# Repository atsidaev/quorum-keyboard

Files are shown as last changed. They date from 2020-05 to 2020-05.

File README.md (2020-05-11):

# Мини-клавиатура для Кворум-128

Пленка в клавиатуре Кворума-128 не очень прочна и много у кого уже умерла. На правах костыля можно заменить такую клавиатуру
на текстолитовый суррогат. Для установки требуется выпаять оргинальные разъемы и заменить их на штыри PLS.

# Mini-keyboard for Quorum-128 computer (Russian clone of ZX Spectrum)

Quorum-128 keyboard film is not very durable. But despite the Sinclair ZX Spectrum film, it cannot be simply bought on eBay.
So more radical solution is required.

This repo contains KiCad sources for very small repalcement keyboard. To install it one should replace film connector with
PLS pins.

## Explanation and soldering video

Youtube link (https://www.youtube.com/watch?v=iXpktqWTcs8)

## Photos
  
  
  
  
  

## Gerbers

See Releases tab. 
[Latest version](https://github.com/atsidaev/quorum_keyboard/releases/download/v1.0/quorum-keyboard.zip)

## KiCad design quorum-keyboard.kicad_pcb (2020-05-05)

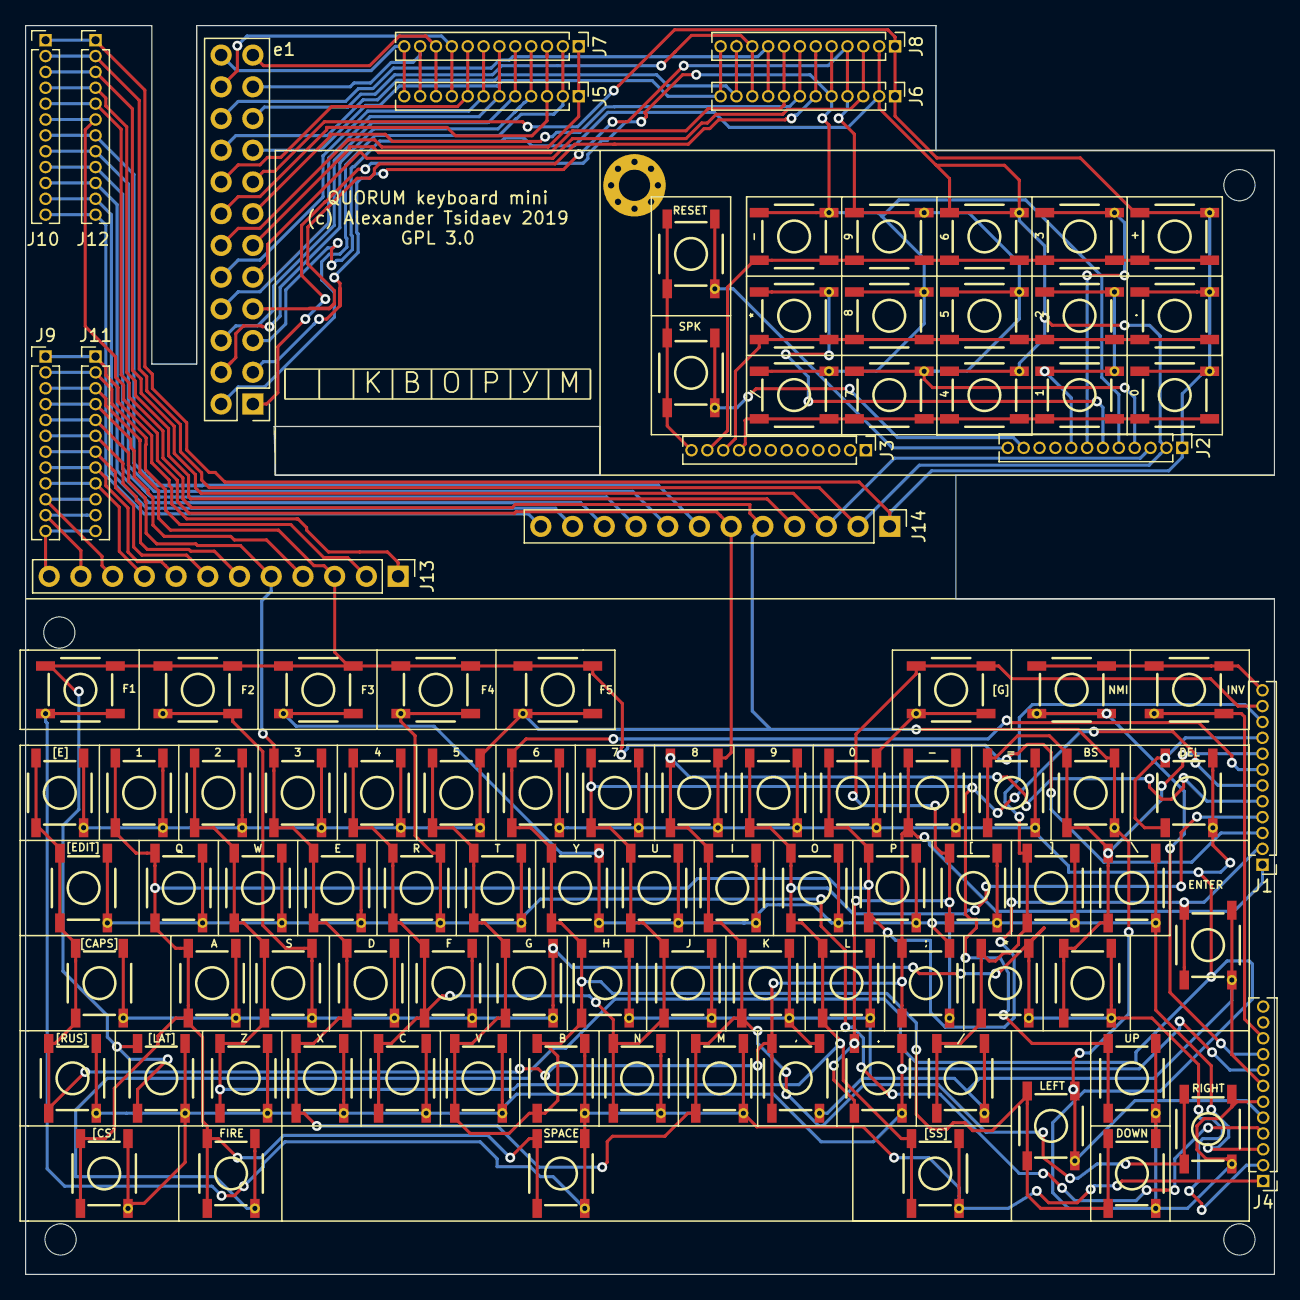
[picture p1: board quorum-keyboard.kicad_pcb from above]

Board: 2 copper layers, 100.0 x 100.0 mm, 107 parts (0 on the bottom side), 24 nets.

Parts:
0, 0#2, 1, 1#2, 2, 2#2, 3, 3#2, 4, 4#2, 5, 5#2, 6, 6#2, 7, 7#2, 8, 8#2, 9, 9#2, ., .#2: QKB_TACTILE_SWITCH_SMD_5.2MM
 : MountingHole_2.5mm
 #2,  #3: MountingHole_2.5mm
*: QKB_TACTILE_SWITCH_SMD_5.2MM
*#2: QKB_TACTILE_SWITCH_SMD_5.2MM
+: QKB_TACTILE_SWITCH_SMD_5.2MM
,: QKB_TACTILE_SWITCH_SMD_5.2MM
-: QKB_TACTILE_SWITCH_SMD_5.2MM
-#2: QKB_TACTILE_SWITCH_SMD_5.2MM
/: QKB_TACTILE_SWITCH_SMD_5.2MM
/#2: QKB_TACTILE_SWITCH_SMD_5.2MM
;: QKB_TACTILE_SWITCH_SMD_5.2MM
=: QKB_TACTILE_SWITCH_SMD_5.2MM
A: QKB_TACTILE_SWITCH_SMD_5.2MM
B: QKB_TACTILE_SWITCH_SMD_5.2MM
BS: QKB_TACTILE_SWITCH_SMD_5.2MM
C: QKB_TACTILE_SWITCH_SMD_5.2MM
D: QKB_TACTILE_SWITCH_SMD_5.2MM
DEL: QKB_TACTILE_SWITCH_SMD_5.2MM
DOWN: QKB_TACTILE_SWITCH_SMD_5.2MM
E: QKB_TACTILE_SWITCH_SMD_5.2MM
ENTER: QKB_TACTILE_SWITCH_SMD_5.2MM
F, F1, F2, F3, F4, F5: QKB_TACTILE_SWITCH_SMD_5.2MM
FIRE: QKB_TACTILE_SWITCH_SMD_5.2MM
G: QKB_TACTILE_SWITCH_SMD_5.2MM
H: QKB_TACTILE_SWITCH_SMD_5.2MM
H3: MountingHole_2.5mm
H4: MountingHole_2.5mm_Pad_Via
I: QKB_TACTILE_SWITCH_SMD_5.2MM
INV: QKB_TACTILE_SWITCH_SMD_5.2MM
J: QKB_TACTILE_SWITCH_SMD_5.2MM
J1, J2, J3, J4, J5, J6, J7, J8, J9, J10, J11, J12: Pin_Header_Straight_1x12_Pitch1.27mm
J13, J14: Pin_Header_Straight_1x12_Pitch2.54mm
K: QKB_TACTILE_SWITCH_SMD_5.2MM
L: QKB_TACTILE_SWITCH_SMD_5.2MM
LEFT: QKB_TACTILE_SWITCH_SMD_5.2MM
M: QKB_TACTILE_SWITCH_SMD_5.2MM
N: QKB_TACTILE_SWITCH_SMD_5.2MM
NMI: QKB_TACTILE_SWITCH_SMD_5.2MM
O: QKB_TACTILE_SWITCH_SMD_5.2MM
P: QKB_TACTILE_SWITCH_SMD_5.2MM
Q: QKB_TACTILE_SWITCH_SMD_5.2MM
R: QKB_TACTILE_SWITCH_SMD_5.2MM
RESET: QKB_TACTILE_SWITCH_SMD_5.2MM
RIGHT: QKB_TACTILE_SWITCH_SMD_5.2MM
S: QKB_TACTILE_SWITCH_SMD_5.2MM
SPACE: QKB_TACTILE_SWITCH_SMD_5.2MM
SPK: QKB_TACTILE_SWITCH_SMD_5.2MM
T: QKB_TACTILE_SWITCH_SMD_5.2MM
U: QKB_TACTILE_SWITCH_SMD_5.2MM
UP: QKB_TACTILE_SWITCH_SMD_5.2MM
V: QKB_TACTILE_SWITCH_SMD_5.2MM
W: QKB_TACTILE_SWITCH_SMD_5.2MM
X: QKB_TACTILE_SWITCH_SMD_5.2MM
Y: QKB_TACTILE_SWITCH_SMD_5.2MM
Z: QKB_TACTILE_SWITCH_SMD_5.2MM
[: QKB_TACTILE_SWITCH_SMD_5.2MM
[CAPS]: QKB_TACTILE_SWITCH_SMD_5.2MM
[CS]: QKB_TACTILE_SWITCH_SMD_5.2MM
[EDIT]: QKB_TACTILE_SWITCH_SMD_5.2MM
[E]: QKB_TACTILE_SWITCH_SMD_5.2MM
[G]: QKB_TACTILE_SWITCH_SMD_5.2MM
[LAT]: QKB_TACTILE_SWITCH_SMD_5.2MM
[RUS]: QKB_TACTILE_SWITCH_SMD_5.2MM
[SS]: QKB_TACTILE_SWITCH_SMD_5.2MM
\: QKB_TACTILE_SWITCH_SMD_5.2MM
]: QKB_TACTILE_SWITCH_SMD_5.2MM
e1: Pin_Header_Straight_2x12_Pitch2.54mm

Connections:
A8: 1.3, 1.4, 2.3, 2.4, .#2.3, .#2.4, C.3, C.4, J2.8, J4.8, J6.8, J8.8, J10.8, J12.8, J14.8, V.3, V.4, X.3, X.4, Z.3, Z.4, [CS].3, [CS].4, [LAT].3, [LAT].4, [RUS].3, [RUS].4, e1.11
A9: 4.3, 4.4, 6.3, 6.4, *#2.3, *#2.4, A.3, A.4, D.3, D.4, F.3, F.4, F2.3, F2.4, G.3, G.4, J2.2, J4.2, J6.2, J8.2, J10.2, J12.2, J14.2, S.3, S.4, [CAPS].3, [CAPS].4, e1.5
A10: 5.3, 5.4, 7.3, 7.4, 9.3, 9.4, E.3, E.4, F4.3, F4.4, J2.4, J4.4, J6.4, J8.4, J10.4, J12.4, J14.4, Q.3, Q.4, R.3, R.4, T.3, T.4, W.3, W.4, [EDIT].3, [EDIT].4, e1.3
A11: 1#2.3, 1#2.4, 2#2.3, 2#2.4, 3#2.3, 3#2.4, 4#2.3, 4#2.4, 5#2.3, 5#2.4, 8.3, 8.4, -.3, -.4, /.3, /.4, BS.3, BS.4, F5.3, F5.4, J2.5, J4.5, J6.5, J8.5, J10.5, J12.5, J14.5, LEFT.3, LEFT.4, [E].3, [E].4, e1.1
A12: 0#2.3, 0#2.4, 6#2.3, 6#2.4, 7#2.3, 7#2.4, 8#2.3, 8#2.4, 9#2.3, 9#2.4, *.3, *.4, -#2.3, -#2.4, =.3, =.4, DEL.3, DEL.4, DOWN.3, DOWN.4, FIRE.3, FIRE.4, J2.6, J4.6, J6.6, J8.6, J10.6, J12.6, J14.6, RIGHT.3, RIGHT.4, UP.3, UP.4, [G].3, [G].4, e1.7
A13: ;.3, ;.4, F3.3, F3.4, I.3, I.4, J2.3, J4.3, J6.3, J8.3, J10.3, J12.3, J14.3, O.3, O.4, P.3, P.4, U.3, U.4, Y.3, Y.4, [.3, [.4, \.3, \.4, ].3, ].4, e1.9
A14: 3.3, 3.4, ,.3, ,.4, /#2.3, /#2.4, ENTER.3, ENTER.4, H.3, H.4, J.3, J.4, J2.7, J4.7, J6.7, J8.7, J10.7, J12.7, J14.7, K.3, K.4, L.3, L.4, e1.13
A15: 0.3, 0.4, +.3, +.4, ..3, ..4, B.3, B.4, F1.3, F1.4, J2.1, J4.1, J6.1, J8.1, J10.1, J12.1, J14.1, M.3, M.4, N.3, N.4, SPACE.3, SPACE.4, [SS].3, [SS].4, e1.15
D0: 0#2.1, 0#2.2, 1#2.1, 1#2.2, A.1, A.2, ENTER.1, ENTER.2, FIRE.1, FIRE.2, J1.2, J3.2, J5.2, J7.2, J9.2, J11.2, J13.2, P.1, P.2, Q.1, Q.2, SPACE.1, SPACE.2, [CS].1, [CS].2, e1.2
D0*: ,.1, ,.2, -#2.1, -#2.2, ;.1, ;.2, J1.1, J3.1, J5.1, J7.1, J9.1, J11.1, J13.1, [CAPS].1, [CAPS].2, [EDIT].1, [EDIT].2, [E].1, [E].2, [RUS].1, [RUS].2, e1.12
D1: 2#2.1, 2#2.2, 9#2.1, 9#2.2, J1.4, J3.4, J5.4, J7.4, J9.4, J11.4, J13.4, L.1, L.2, O.1, O.2, S.1, S.2, W.1, W.2, Z.1, Z.2, [SS].1, [SS].2, e1.4
D1*: F1.1, F1.2, F2.1, F2.2, F3.1, F3.2, F4.1, F4.2, F5.1, F5.2, J1.3, J3.3, J5.3, J7.3, J9.3, J11.3, J13.3, [LAT].1, [LAT].2, e1.14
D2: 3#2.1, 3#2.2, 8#2.1, 8#2.2, D.1, D.2, E.1, E.2, I.1, I.2, J1.5, J3.5, J5.5, J7.5, J9.5, J11.5, J13.5, K.1, K.2, M.1, M.2, RIGHT.1, RIGHT.2, X.1, X.2, e1.6
D2*: =.1, =.2, BS.1, BS.2, J1.8, J3.8, J5.8, J7.8, J9.8, J11.8, J13.8, \.1, \.2, e1.16
D3: 4#2.1, 4#2.2, 7#2.1, 7#2.2, C.1, C.2, F.1, F.2, J.1, J.2, J1.6, J3.6, J5.6, J7.6, J9.6, J11.6, J13.6, N.1, N.2, R.1, R.2, U.1, U.2, UP.1, UP.2, e1.8
D3*: 0.1, 0.2, 1.1, 1.2, 4.1, 4.2, 7.1, 7.2, /.1, /.2, DEL.1, DEL.2, J1.9, J3.9, J5.9, J7.9, J9.9, J11.9, J13.9, e1.22
D4: 5#2.1, 5#2.2, 6#2.1, 6#2.2, B.1, B.2, DOWN.1, DOWN.2, G.1, G.2, H.1, H.2, J1.7, J3.7, J5.7, J7.7, J9.7, J11.7, J13.7, LEFT.1, LEFT.2, T.1, T.2, V.1, V.2, Y.1, Y.2, e1.10
D4*: 2.1, 2.2, 5.1, 5.2, 8.1, 8.2, *.1, *.2, *#2.1, *#2.2, ..1, ..2, /#2.1, /#2.2, J1.10, J3.10, J5.10, J7.10, J9.10, J11.10, J13.10, ].1, ].2, e1.23
D5*: 3.1, 3.2, 6.1, 6.2, 9.1, 9.2, +.1, +.2, -.1, -.2, .#2.1, .#2.2, J1.11, J3.11, J5.11, J7.11, J9.11, J11.11, J13.11, [.1, [.2, [G].1, [G].2, e1.21
GND: INV.1, INV.2, J1.12, J3.12, J5.12, J7.12, J9.12, J11.12, J13.12, NMI.1, NMI.2, RESET.1, RESET.2, SPK.1, SPK.2, e1.24
KINV: INV.3, INV.4, J2.10, J4.10, J6.10, J8.10, J10.10, J12.10, J14.10, e1.19
KNMI: J2.9, J4.9, J6.9, J8.9, J10.9, J12.9, J14.9, NMI.3, NMI.4, e1.20
KSPC: J2.11, J4.11, J6.11, J8.11, J10.11, J12.11, J14.11, SPK.3, SPK.4, e1.18
RES: J2.12, J4.12, J6.12, J8.12, J10.12, J12.12, J14.12, RESET.3, RESET.4, e1.17

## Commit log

2020-05-05 Silkscreen added. No mask on pads at boards contact.
    [quorum-keyboard.kicad_pcb]
2020-05-11 Tactile switch model .gitignore updated

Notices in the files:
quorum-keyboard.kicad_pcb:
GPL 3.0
